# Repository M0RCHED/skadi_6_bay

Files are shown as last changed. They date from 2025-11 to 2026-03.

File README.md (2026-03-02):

# ⚡ Skadi 6-Bay Smart Charger — v1.0 

> Plateforme de gestion intelligente pour 6 packs Li-ion 2S (Excel 2EXL1505 / Skadi).
> Système open hardware permettant la charge et décharge automatique pour atteindre ~30% SoC (conformité IATA/UN 3480).

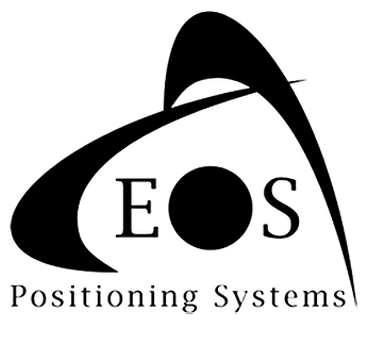
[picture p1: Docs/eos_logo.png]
EOS Logo


---

## 📋 Vue d'ensemble

Les transporteurs internationaux (UPS, FedEx, DHL, etc.) n'acceptent pas l'expédition de batteries Li-ion **> 30 % SoC** en raison des risques thermiques.

Le **Skadi 6-Bay Smart Charger** permet de **ramener automatiquement chaque batterie au seuil de ~30 % SoC**, qu'elle soit initialement trop basse (charge) ou trop haute (décharge via ELOAD externe).

### Fonctionnalités principales

- ✅ **6 baies indépendantes** avec contrôle charge/décharge par MOSFET
- ✅ **Supervision I²C** via multiplexeur TCA9548A + répéteurs TCA9803
- ✅ **Fuel gauge MAX17263** intégré dans chaque pack (SoC, température, tension)
- ✅ **Machine à états finie (FSM)** avec initialisation automatique ModelGauge m5 EZ
- ✅ **Télémétrie BLE** (HC-08) + UART + USB CDC
- ✅ **Affichage LED** par baie via driver PCA9634
- ✅ **Watchdog matériel** (WWDG) pour sécurité

---

## 🔧 Architecture matérielle

### Alimentation
- **Entrée**: 12V DC (fusible 12A rapide)
- **Buck 3.3V**: TPS562200 (12V → 3.3V, 2A)
- **Protection**: TVS, NTC, condensateurs bulk

### Microcontrôleur
- **MCU**: STM32F103C8Tx (ARM Cortex-M3, 48 pins)
- **Horloge**: 16 MHz (cristal externe HSE)
- **Watchdog**: WWDG (Window Watchdog) avec refresh toutes les 10ms
- **Interfaces**:
  - USB 2.0 Type-C (protection USBLC6-2SC6)
  - SWD (Tag-Connect TC2030-NL)
  - UART2 (115200 baud, BLE HC-08)
  - I²C1 (100 kHz)
  - ADC1 (mesure tension 12V)

### Gestion des baies (×6)

Chaque baie dispose de:
- **Commutation charge**: P-MOSFET AO4407A + driver N-MOSFET DMG2302U
- **Commutation décharge**: P-MOSFET AO4407A + driver N-MOSFET DMG2302U
- **Répéteur I²C**: TCA9803 (isolation 3.3V ↔ pack)
- **Protection**: Diodes 1N4148WT, résistances de limitation
- **Points de test**: CHG_GATE, DIS_GATE
- **Connecteur**: 2 broches pogo pins (BAT+/BAT-)

### Multiplexage I²C
- **Circuit**: TCA9548APWR (8 canaux, 6 utilisés)
- **Fonction**: Communication I²C individuelle avec chaque pack
- **Pull-ups**: 2.2kΩ sur bus principal, 10kΩ sur multiplexeur

### Pilotage des LEDs
- **Driver**: PCA9634PW (8 canaux PWM)
- **Résistances**: 680Ω par LED
- **Contrôle**: Via I²C depuis MCU

---

## 🧠 Architecture Firmware

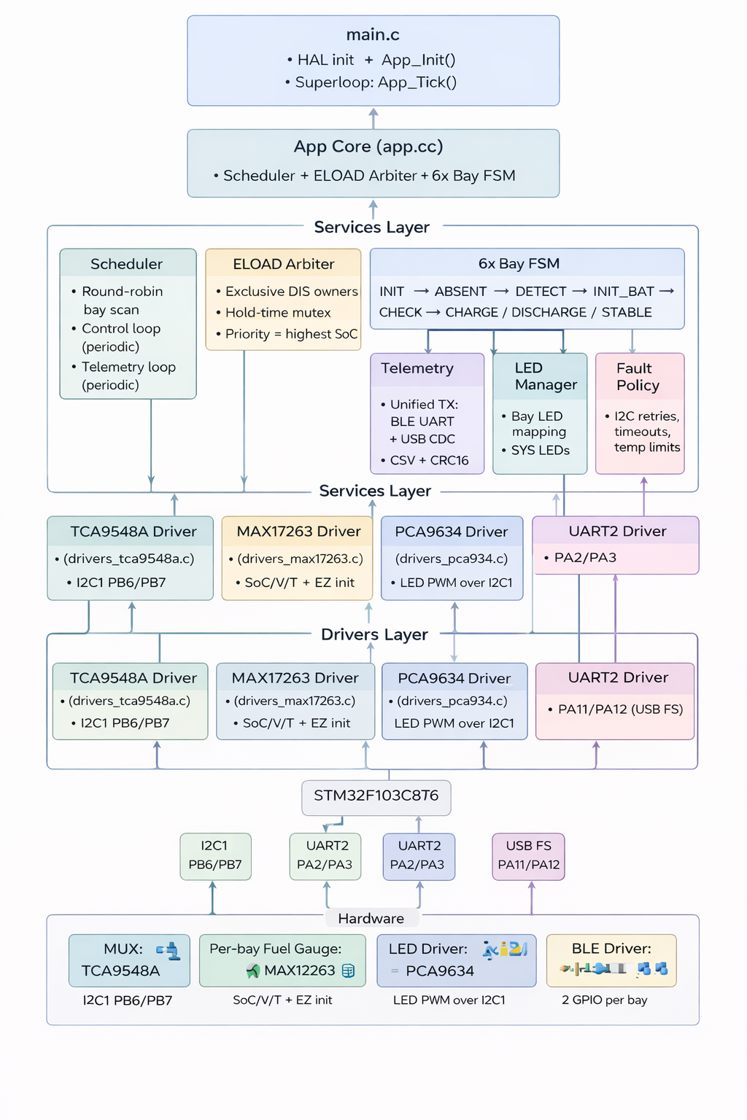
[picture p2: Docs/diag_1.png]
Diagramme d'architecture firmware


### Structure du code

```
firmware/
├── Core/
│   ├── Src/
│   │   ├── main.c              # Point d'entrée, init périphériques
│   │   ├── stm32f1xx_it.c      # Interruptions
│   │   └── system_stm32f1xx.c  # Config système
│   └── Inc/
├── App/
│   ├── app.c                   # Machine à états principale
│   ├── app_config.h            # Constantes (seuils, timeouts)
│   ├── board_io.c              # Abstraction GPIO/ADC
│   ├── drivers_tca9548a.c      # Driver MUX I²C
│   ├── drivers_max17263.c      # Driver fuel gauge
│   ├── drivers_pca9634.c       # Driver LEDs
│   ├── services_cmd.c          # Parser commandes BLE/UART
│   ├── services_led.c          # Logique LEDs
│   ├── services_telemetry.c    # Télémétrie UART/USB
│   └── services_identity.c     # UID unique STM32
└── USB_DEVICE/                 # Stack USB CDC
```

### Boucle principale (main.c)

```c
void main(void) {
  HAL_Init();
  SystemClock_Config();  // HSE 16MHz → PLL 48MHz
  
  // Init périphériques
  MX_GPIO_Init();
  MX_ADC1_Init();
  MX_I2C1_Init();        // 100kHz
  MX_USART2_UART_Init(); // 115200 baud
  MX_WWDG_Init();        // Watchdog
  MX_USB_DEVICE_Init();  // CDC
  
  App_Init(&g_app);
  HAL_UART_Receive_IT(&huart2, &ble_rx_byte, 1);
  
  while(1) {
    if ((HAL_GetTick() - t0) >= 10ms) {  // Tick 10ms
      t0 = HAL_GetTick();
      App_Tick(&g_app);                  // FSM principale
      HAL_WWDG_Refresh(&hwwdg);          // Feed watchdog
    }
  }
}
```

### Machine à états finie (FSM)

Le firmware implémente une FSM par baie avec **scan round-robin** (une baie à la fois, cycle de 5s/baie).

#### États de la FSM

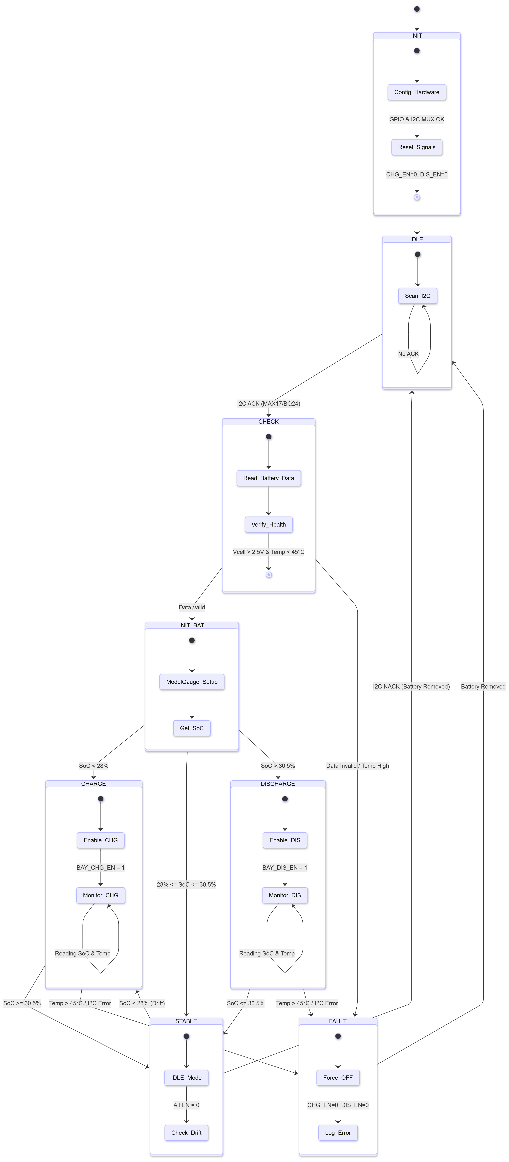
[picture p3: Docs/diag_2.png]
Diagramme FSM


#### Description des états

| État | Description | Transitions |
|---|---|---|
| **INIT** | Initialisation système, reset des GPIO | → ABSENT (pack absent)<br>→ CHECK (pack détecté) |
| **IDLE** | Pack non détecté (DET=0 ou I²C NACK) | → CHECK (insertion pack) |
| **CHECK** | Lecture I²C initiale, vérification température | → INIT_BAT (I²C OK)<br>→ FAULT (I²C fail > 3×) |
| **INIT_BAT** | **Initialisation ModelGauge m5 EZ**<br>• Appel `Gauge_EZ_Init()`<br>• Configuration fuel gauge | → CHARGE (SoC < 28%)<br>→ DISCHARGE (SoC > 30.5%)<br>→ STABLE (28% ≤ SoC ≤ 30.5%)<br>→ FAULT (erreur init) |
| **CHARGE** | 12V activé, charge CC/CV par BQ24610 | → STABLE (SoC ≥ 30.5%)<br>→ FAULT (timeout 25min, T>45°C) |
| **DISCHARGE** | ELOAD actif (une baie à la fois) | → STABLE (SoC ≤ 30.5%)<br>→ FAULT (timeout 20min, T>45°C) |
| **STABLE** | SoC autour de 30%, repos | → CHARGE (SoC < 28%)<br>→ DISCHARGE (SoC > 30.5%) |
| **FAULT** | Erreur (température, I²C, timeout) | → CHECK (récupération auto si T<40°C, I²C OK) |

### Paramètres d'exploitation (app_config.h)

```c
// Seuils SoC
#define SOC_LOW_START      28.0f    // Démarrer charge
#define SOC_STABLE_HIGH    30.5f    // Arrêter charge/décharge
#define SOC_DISCH_START    30.5f    // Démarrer décharge

// Seuils température
#define TEMP_MAX_C         45.0f    // Coupure sécurité
#define TEMP_RECOVER_C     40.0f    // Récupération auto

// Timeouts
#define CHG_TIMEOUT_MS     (25u * 60u * 1000u)  // 25 min
#define DIS_TIMEOUT_MS     (20u * 60u * 1000u)  // 20 min

// Périodes
#define SCAN_PERIOD_MS_PER_BAY  5000u   // 5s/baie
#define CTRL_PERIOD_MS          100u    // 100ms (FSM)
#define TELEMETRY_PERIOD_MS     5000u   // 5s

// I²C
#define I2C_RETRY_MAX          3u
#define I2C_RETRY_DELAY_MS     50u
```

### Arbitrage ELOAD

**Règle**: Une seule baie à la fois peut être connectée à l'ELOAD.

```c
void eload_select_set(app_t *a, uint8_t allow_dis[BAY_COUNT])
{
  // Sélectionner jusqu'à eload_slots baies (1 par défaut)
  // Prioriser la baie avec le SoC le plus élevé
  
  for (uint8_t slot = 0; slot < a->eload_slots; slot++) {
    float best_soc = SOC_DISCH_START;
    int best_bay = -1;
    
    for (uint8_t i = 0; i < BAY_COUNT; i++) {
      if (allow_dis[i]) continue;           // Déjà sélectionnée
      if (!bay[i].present || !bay[i].i2c_ok) continue;
      if (bay[i].state == BAY_S_FAULT) continue;
      if (bay[i].temp_c >= TEMP_MAX_C) continue;
      if (bay[i].soc <= SOC_DISCH_START) continue;
      
      if (bay[i].soc > best_soc) {
        best_soc = bay[i].soc;
        best_bay = i;
      }
    }
    
    if (best_bay >= 0) allow_dis[best_bay] = 1;
  }
}
```

### Initialisation ModelGauge m5 EZ

**État INIT_BAT**: Après détection du pack et lecture I²C réussie, le firmware initialise le fuel gauge:

```c
// drivers_max17263.c
HAL_StatusTypeDef Gauge_EZ_Init(void)
{
  // 1. Soft reset (optionnel)
  // i2c_w16(0x60, 0x000F);  // Command = 0x000F
  // HAL_Delay(200);
  
  // 2. Configuration ModelGauge m5 EZ
  // i2c_w16(0xDB, 0x8000);  // ModelCfg = 0x8000 (EZ mode)
  // HAL_Delay(2000);        // Attendre convergence modèle
  
  // 3. Paramètres pack (exemples)
  // i2c_w16(0x18, 3300);    // DesignCap = 3300 mAh
  // i2c_w16(0x23, 8400);    // VEmpty = 5.0V (2×2.5V)
  
  // Pour l'instant, retour OK (à compléter selon datasheet)
  return HAL_OK;
}
```

**Note**: L'implémentation complète sera finalisée avec les paramètres exacts du pack Excel 2EXL1505.

### Télémétrie

Format CSV avec CRC16-CCITT envoyé toutes les 5s par baie:

```
UID,<24_hex_chars>,TS,<ms>,BAY,<1-6>,ST,<état>,SOC_D10,<0.1%>,VCELL_MV,<mV>,TEMP_D10,<0.1°C>,PRES,<0|1>,I2C,<0|1>,ERR,<code>,ELOADS,<slots>,VIN_CV,<cV>,CRC,<hex>
```

**Exemple**:
```
UID,2A01C3F08B1D77AA0019FF10,TS,123456,BAY,3,ST,DIS,SOC_D10,472,VCELL_MV,7730,TEMP_D10,314,PRES,1,I2C,1,ERR,0,ELOADS,1,VIN_CV,1215,CRC,A3F2
```

### Commandes BLE/UART

Format texte simple:

```
ELOADS=<1-6>   # Nombre de baies ELOAD simultanées
MODE=30        # Mode ~30% SoC (défaut)
MODE=100       # Mode charge 100%
```

---

## 📊 Schémas du PCB

Le projet contient 7 pages de schémas KiCad:

1. **Page 1**: Vue d'ensemble (hiérarchie des feuilles)
2. **Page 2**: Alimentation 12V → Buck 3.3V
3. **Page 3**: MCU STM32F103C8T + USB + SWD + BLE
4. **Page 4**: Multiplexeur I²C TCA9548A
5. **Page 5**: Buck converter 3.3V (TPS562200)
6. **Page 6**: Baie #1 (répété ×6)
7. **Page 7**: Driver LEDs PCA9634

---

## 🛠️ Composants principaux

| Référence | Composant | Quantité | Description |
|---|---|---|---|
| U1 | TPS562200 | 1 | Buck 12V→3.3V (2A) |
| U2 | TCA9803 | 6 | Répéteur I²C par baie |
| U3 | USBLC6-2SC6 | 1 | Protection USB |
| U4 | STM32F103C8Tx | 1 | MCU principal (48MHz) |
| U6 | TCA9548APWR | 1 | MUX I²C 8 canaux |
| IC1 | PCA9634PW | 1 | Driver LED 8 canaux |
| Q_CHG1/2 | AO4407A | 12 | P-MOSFET charge (×2/baie) |
| Q_DIS2 | AO4407A | 6 | P-MOSFET décharge |
| Q_CHG/DIS_DRV | DMG2302U | 12 | N-MOSFET driver |
| F1 | Fusible 12A | 1 | Protection entrée |
| D1 | TVS | 1 | Protection surtension |
| Y1 | Cristal 16MHz | 1 | Horloge externe HSE |
| L1 | Inductance 3.3µH | 1 | Buck converter |

---

## 🔌 Pinout MCU (STM32F103C8T)

### Contrôle baies
| Pin | Signal | Fonction |
|-----|---|---|
| PA0 | BAY1_CHG_EN | Enable charge baie 1 |
| PA1 | BAY2_CHG_EN | Enable charge baie 2 |
| PA2 | BAY3_CHG_EN | Enable charge baie 3 |
| PA3 | BAY4_CHG_EN | Enable charge baie 4 |
| PA4 | BAY1_DIS_EN | Enable décharge baie 1 |
| PA5 | BAY2_DIS_EN | Enable décharge baie 2 |
| PB0 | BAY5_CHG_EN | Enable charge baie 5 |
| PB1 | BAY6_CHG_EN | Enable charge baie 6 |
| PB10 | BAY6_DIS_EN | Enable décharge baie 6 |
| PB11 | BAY5_DIS_EN | Enable décharge baie 5 |
| PB12 | BAY4_DIS_EN | Enable décharge baie 4 |
| PB13 | BAY3_DIS_EN | Enable décharge baie 3 |

### Communication
| Pin | Signal | Fonction |
|-----|---|---|
| PB6 | I2C1_SCL | Horloge I²C (100kHz) |
| PB7 | I2C1_SDA | Données I²C |
| PA9 | UART_TX | TX vers BLE HC-08 |
| PA10 | UART_RX | RX depuis BLE HC-08 |
| PA11 | USB_D- | USB 2.0 D- |
| PA12 | USB_D+ | USB 2.0 D+ |

### Programmation/Debug
| Pin | Signal | Fonction |
|-----|---|---|
| PA13 | SWDIO | Serial Wire Debug I/O |
| PA14 | SWCLK | Serial Wire Clock |
| PB3 | SWO | Serial Wire Output |
| NRST | NRST | Reset (connecté à superviseur) |

### ADC
| Pin | Signal | Fonction |
|-----|---|---|
| PA0 | ADC_CH0 | Mesure tension 12V (diviseur 133k/33k) |

---

## 📐 Diagramme d'architecture

```
       12V DC Input (12A fusible)
              │
      ┌───────┴───────────┐
      │   Protection      │
      │ • TVS SMBJ15A     │
      │ • Bulk caps       │
      │                   │
      └───────┬───────────┘
              │
      ┌───────┴───────────────────────────────────┐
      │                                           │
      ▼                                           ▼
┌─────────────┐                         ┌──────────────────┐
│ Buck 3.3V   │                         │  6× Bay Switches │
│ TPS562200   │           ┌────────────►│      AO4407A     │
│ (2A)        │     ┌─────┴─────┐       │  (12V high-side) │
└──────┬──────┘     │ DMG2302U  │       └────────┬─────────┘
       │            └─────┬─────┘                │
       ▼                  │                      ▼
┌──────────────────┐      │GPIO x6        ┌──────────────┐
│  STM32F103C8T    │      │               │ Pogo Pins ×6 │
│  • 48MHz         ├──────┤               │ (Batt packs) │
│  • WWDG          │      │               └──────────────┘
│  • 10ms tick     │      │                       │
└────┬─────────────┘      │                       │
     │                    │                       │
	 │                    │                       │
	 │              ┌─────┴─────┐                 │
	 │              │ DMG2302U  ├───────┐         │
	 │              └───────────┘       │         │
	 │                                  ▼         │
	 │                            ┌───────────┐   │ 
	 │                            │ 6 Switches│   │	 
	 │                            │ to ELOAD  │   │
     │                            └───────────┘   │
     │                                            │
     │                                            │
     ├──► TCA9548A (I²C MUX)                      │
	 │         │                                  │	 
	 │         │                                  │
     │         ├──► TCA9803 ×6 ───────────────────┘
     │         │     (Buffers)
     │         │
     │         └──► PCA9634 (LED driver)
     │
	 ├──► ADC
	 │
     ├──► USB Type-C
     │
     └──► UART2 → HC-08 (BLE)
```

---

## 🚀 Utilisation

### Programmation (SWD)

1. Connecter programmeur ST-Link au header Tag-Connect (J2)
2. Pins: VCC, GND, SWDIO, SWCLK, NRST, SWO
3. Flasher avec STM32CubeIDE ou OpenOCD

```bash
# Exemple OpenOCD
openocd -f interface/stlink.cfg -f target/stm32f1x.cfg \
  -c "program firmware.elf verify reset exit"
```

### Configuration I²C

- **TCA9548A** (MUX): Adresse 0x70 (A2=A1=A0=0)
- **MAX17263** (Gauge): Adresse 0x6C (sur chaque canal MUX)
- **PCA9634** (LEDs): Adresse 0x15 (A6-A0 configurables)

### Contrôle via BLE/UART

Connecter terminal série (115200 baud, 8N1):

```
ELOADS=2       # Autoriser 2 baies ELOAD simultanées
MODE=30        # Mode ~30% SoC (défaut)
MODE=100       # Mode charge 100%
```

### Télémétrie

Recevoir les trames CSV toutes les 5s:

```python
import serial

ser = serial.Serial('/dev/ttyUSB0', 115200)
while True:
    line = ser.readline().decode('utf-8').strip()
    print(line)
    # Parser: UID,xxx,TS,yyy,BAY,z,...
```

---

## ⚡ Spécifications électriques

| Paramètre | Valeur | Notes |
|---|---|---|
| Tension d'entrée | 12V DC ±10% | 10.8V min, 13.2V max |
| Courant max | 12A | Fusible rapide |
| Tension logique | 3.3V ±5% | Buck TPS562200 |
| Courant par baie (charge) | ~1.1A @ 12V | Via BQ24610 interne pack |
| Fréquence I²C | 100 kHz | Standard mode |
| Fréquence UART | 115200 baud | 8N1, BLE HC-08 |
| Watchdog timeout | ~50ms | WWDG, refresh 10ms |
| Horloge système | 48 MHz | HSE 16MHz + PLL×6 |

---

## 🔒 Protections & Sécurité

| Protection | Implémentation | Réaction |
|---|---|---|
| **Surtension 12V** | TVS SMBJ15A | Écrêtage transitoires |
| **Surcourant** | Fusible 12A rapide | Coupure permanente |
| **Température pack** | MAX17263 + NTC | OFF charge/décharge si >45°C |
| **Watchdog** | WWDG matériel | Reset MCU si crash firmware |
| **Timeout charge** | Software, 25 min | → FAULT |
| **Timeout décharge** | Software, 20 min | → FAULT |
| **Erreur I²C** | 3 retry + isolation baie | → FAULT si persiste |
| **USB** | USBLC6-2SC6 | ESD protection |

---

## 🧪 Tests & Validation

### Checklist matérielle

- [ ] Continuité pistes 12V / GND
- [ ] Court-circuits (test DRC KiCad)
- [ ] Polarité condensateurs électrolytiques
- [ ] Orientation MOSFETs, diodes, ICs
- [ ] Soudure pogo pins

### Checklist firmware

- [ ] Communication I²C avec TCA9548A
- [ ] Sélection canaux MUX (0-5)
- [ ] Lecture MAX17263 (SoC, V, T)
- [ ] Initialisation ModelGauge m5 EZ
- [ ] Commutation MOSFETs charge/décharge
- [ ] Télémétrie UART/USB
- [ ] Watchdog (test crash volontaire)
- [ ] LEDs (états FSM)
- [ ] Commandes BLE

### Procédure de test

1. **Test bench**:
   - Alim 12V/12A
   - 6× packs Skadi (SoC variés: 20%, 35%, 50%, etc.)
   - ELOAD programmable (mode CC, 0.5-1A)
   - Multimètre, oscilloscope
   - Terminal série (UART/BLE)

2. **Scénarios**:
   - Pack vide (10%) → CHARGE → STABLE (30%)
   - Pack plein (80%) → DISCHARGE → STABLE (30%)
   - Insertion/retrait pack → transitions ABSENT/CHECK
   - Surchauffe simulée (chauffer NTC) → FAULT
   - Déconnexion I²C → FAULT après 3 retry

---

## 📂 Structure du dépôt

```
Skadi-6Bay-Charger/
├── hardware/
│   ├── 6_bay_charg.kicad_pcb       # Layout PCB
│   ├── 6_bay_charg.kicad_sch       # Schéma racine
│   ├── Power.kicad_sch             # Alim 12V/3.3V
│   ├── MCU.kicad_sch               # MCU + USB + SWD
│   ├── MUX.kicad_sch               # TCA9548A
│   ├── Buck_3.3V.kicad_sch         # TPS562200
│   ├── bay1.kicad_sch              # Baie type
│   ├── LEDs_driver.kicad_sch       # PCA9634
│   └── bom/                        # Bill of Materials
├── firmware/
│   ├── Core/
│   │   ├── Src/main.c
│   │   └── Inc/main.h
│   ├── App/
│   │   ├── app.c                   # FSM principale
│   │   ├── app_config.h            # Constantes
│   │   ├── board_io.c              # GPIO/ADC
│   │   ├── drivers_tca9548a.c
│   │   ├── drivers_max17263.c
│   │   ├── drivers_pca9634.c
│   │   ├── services_cmd.c
│   │   ├── services_led.c
│   │   ├── services_telemetry.c
│   │   └── services_identity.c
│   └── USB_DEVICE/
├── docs/
│   ├── eos_logo.png
│   ├── datasheets/
│   └── images/
├── README.md
└── LICENSE
```

---

## 🔧 Développement

### Prérequis

- **Hardware**: ST-Link V2/V3, alimentation 12V/12A
- **Software**:
  - STM32CubeIDE (ou Keil, IAR)
  - KiCad 7.0+
  - Terminal série (PuTTY, minicom)

### Build firmware

```bash
cd firmware
# Importer projet dans STM32CubeIDE
# Build → Release
# Flash via ST-Link
```

### Modification schémas

```bash
cd hardware
kicad 6_bay_charg.kicad_pro
# Modifier schémas
# Générer netlist
# Update PCB
```

---

## 🐛 Dépannage

| Problème | Cause probable | Solution |
|---|---|---|
| Pas de détection pack | Pogo pins mal alignés | Vérifier mécanique, continuité |
| I²C timeout | Pull-ups manquants/trop faibles | Ajouter 2.2kΩ, vérifier soudures TCA9803 |
| SoC erroné | MAX17263 non initialisé | Vérifier `Gauge_EZ_Init()`, lire ModelCfg |
| Reset MCU fréquent | Watchdog non rafraîchi | Vérifier tick 10ms
...

## 📌 Limitations connues & évolutions prévues

### Limitations actuelles (v1.0)

- 🔸 **Une seule ELOAD active à la fois**  
  Par défaut, une seule baie peut être connectée à la charge électronique externe pour la décharge.  
  👉 Ce comportement est **logiciel** et **configurable**.

- 🔸 **Pas de stockage persistant des statistiques**  
  Les cycles charge/décharge, fautes et durées ne sont pas encore sauvegardés en Flash interne.

- 🔸 **Interface utilisateur minimale**  
  Le système est volontairement headless (BLE / UART / USB CDC uniquement).

---

### Évolutions prévues (roadmap)

- 🔧 **Décharge multi-baies configurable**  
  Possibilité d’autoriser **N baies simultanées en décharge** (`ELOADS=<1..6>`), avec :
  - arbitrage dynamique,
  - respect du budget PSU,
  - priorisation par SoC.

- 💾 **Journalisation Flash (event log)**  
  Stockage persistant :
  - erreurs par baie,
  - durées de charge/décharge,
  - nombre de cycles.

- 📊 **Interface PC / Web**  
  - Outil desktop (USB CDC) ou web (BLE) pour :
    - monitoring temps réel,
    - export CSV,
    - mise à jour firmware.

- 🌡️ **Gestion thermique avancée**
  - Ventilateur PWM proportionnel,
  - réduction automatique du nombre de baies actives en cas de montée thermique.

- 🔐 **Sécurité & production**
  - CRC firmware,
  - versioning hardware/firmware,
  - numéro de série exposé via BLE/USB.

---

## 🧾 Conformité & usage prévu

- ✔️ **Conformité IATA / UN 3480**  
  Le mode **~30 % SoC** est spécifiquement conçu pour le transport aérien sécurisé.

- ⚠️ **Usage interne / professionnel**  
  Ce projet est destiné à un **environnement contrôlé** ( production, maintenance).  

---

## 📄 Licence

Ce projet est publié sous licence **MIT** :

- Utilisation libre (personnelle / commerciale)

Voir le fichier `LICENSE` pour le texte complet.

---

## 🤝 Contributions

Les contributions sont bienvenues :

- amélioration firmware (FSM, drivers),
- validation thermique,
- optimisation hardware,
- outils de monitoring.

Merci d’ouvrir une **issue** ou une **pull request** avec une description claire.

---

## ✍️ Auteur

**Takiyeddin Gherras**  

© 2026 EOS Positioning Systems

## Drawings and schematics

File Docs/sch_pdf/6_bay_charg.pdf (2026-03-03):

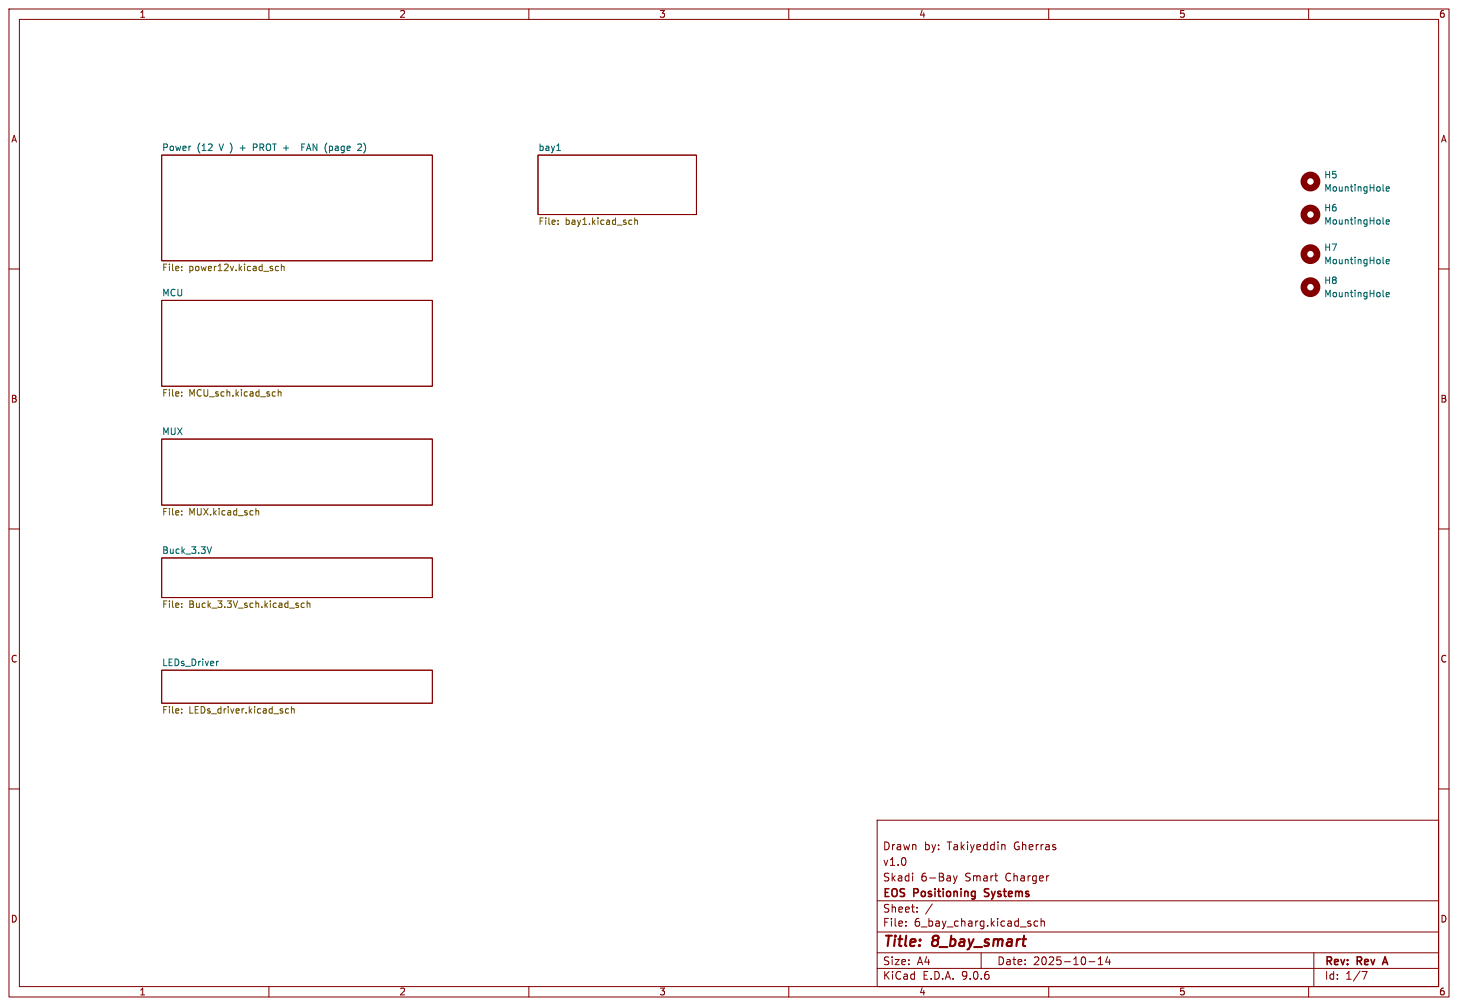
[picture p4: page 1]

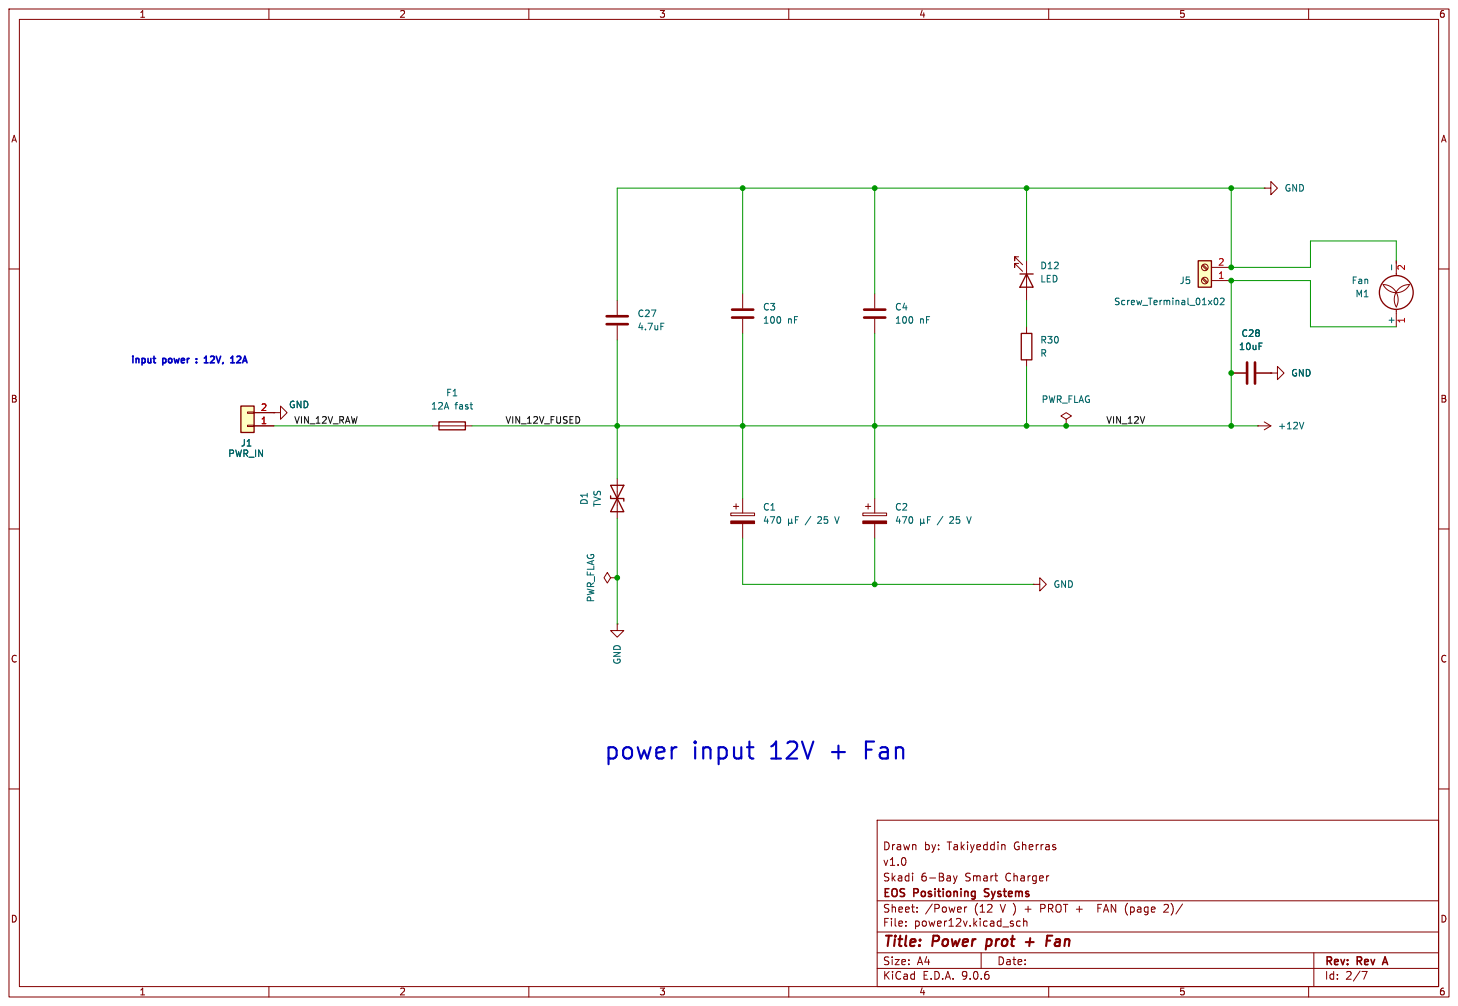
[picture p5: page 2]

Id: 2/7 Title: Power prot + Fan

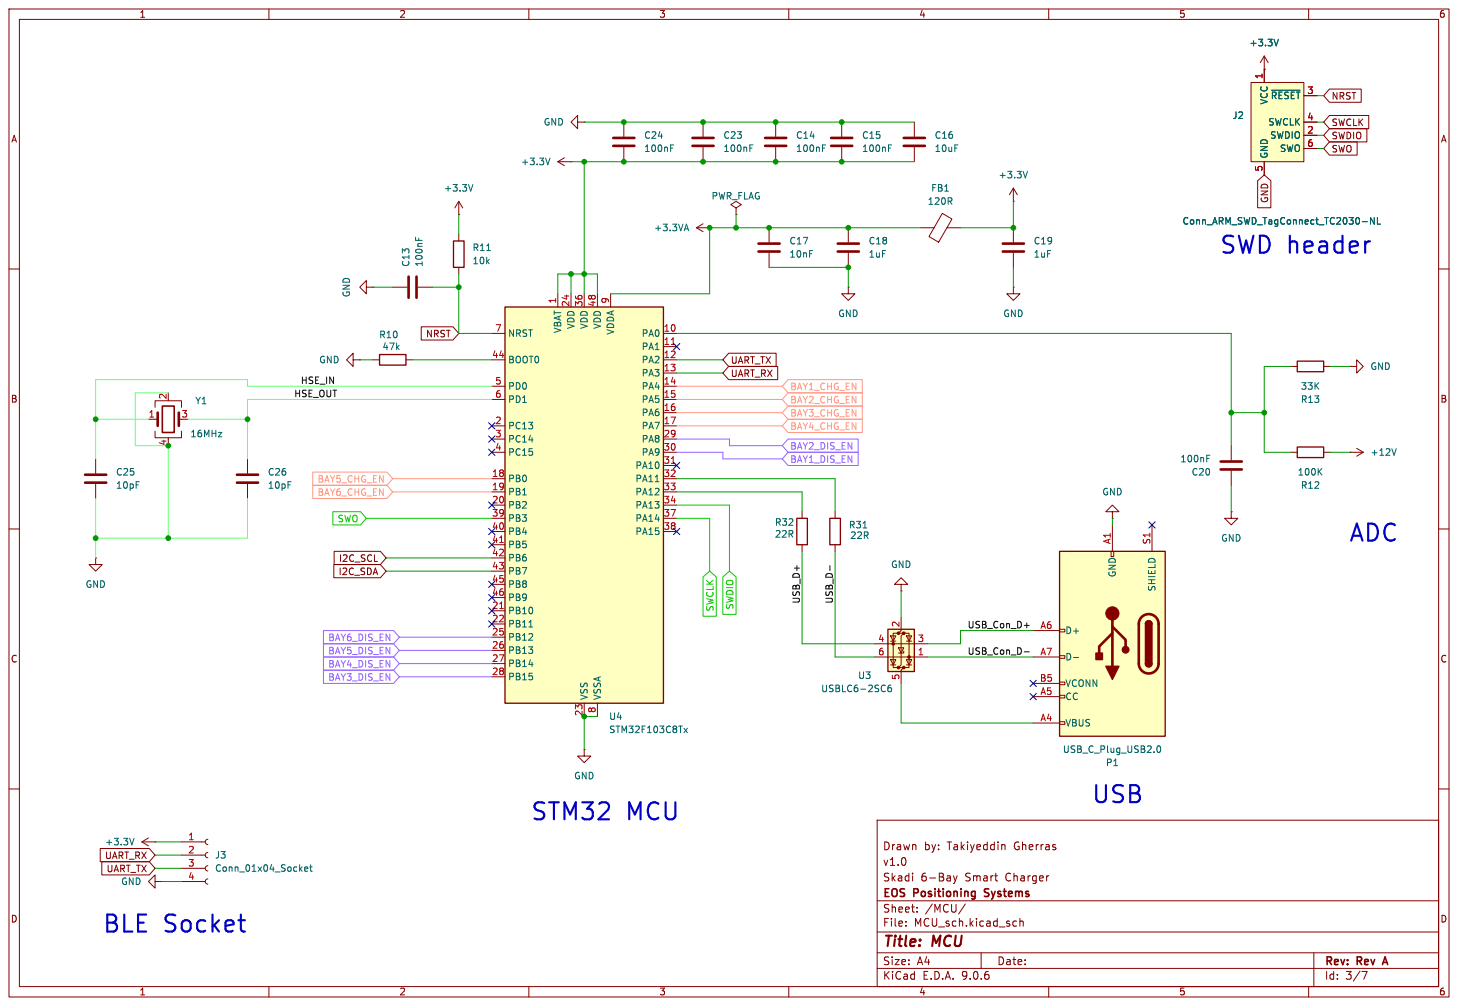
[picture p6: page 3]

5 ~{RESET}3 SWCLK 4 SWDIO 2 SWO 6 +3.3V

5 ~{RESET}3 SWCLK 4 SWDIO 2 SWO 6

1 VDD 24 VDD 36 VSS 23 VDD 48 VSSA

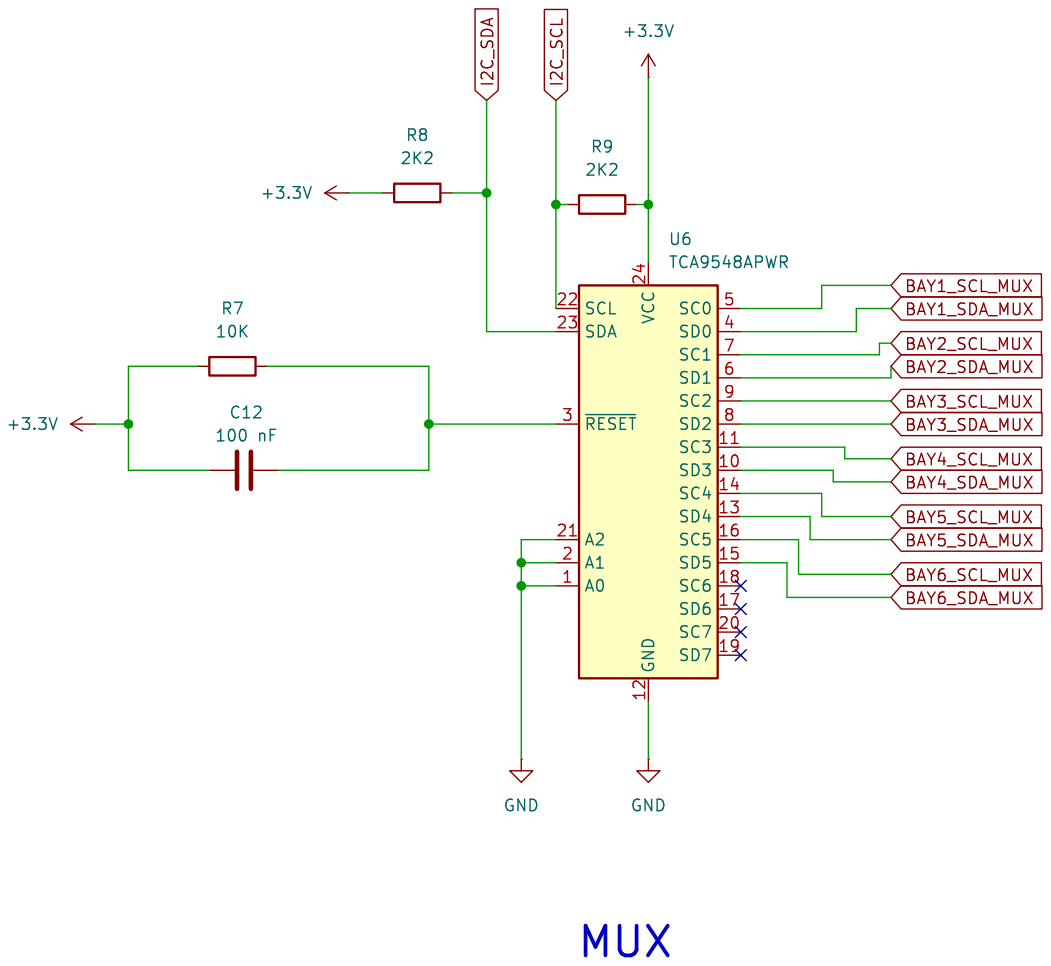
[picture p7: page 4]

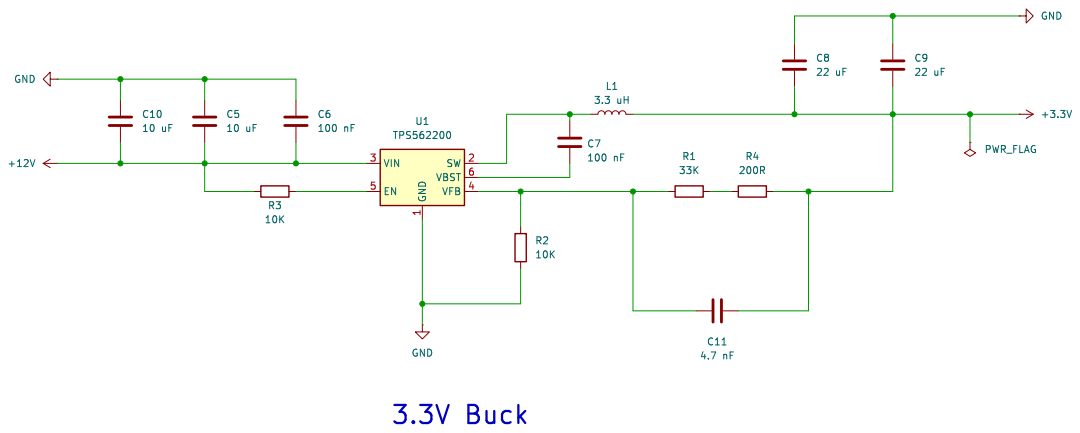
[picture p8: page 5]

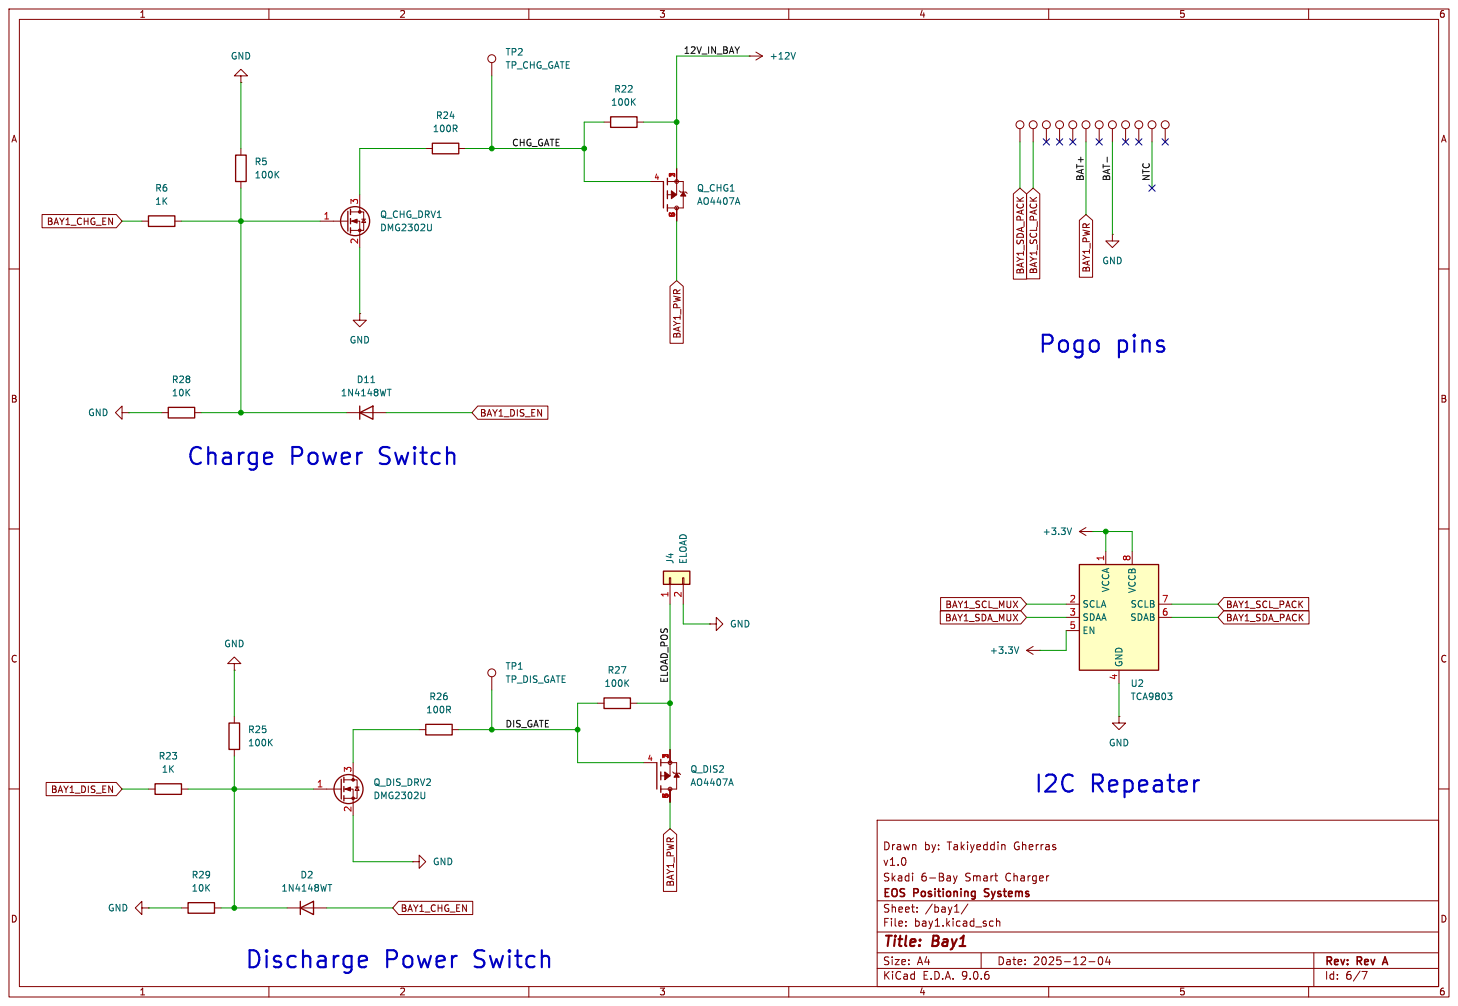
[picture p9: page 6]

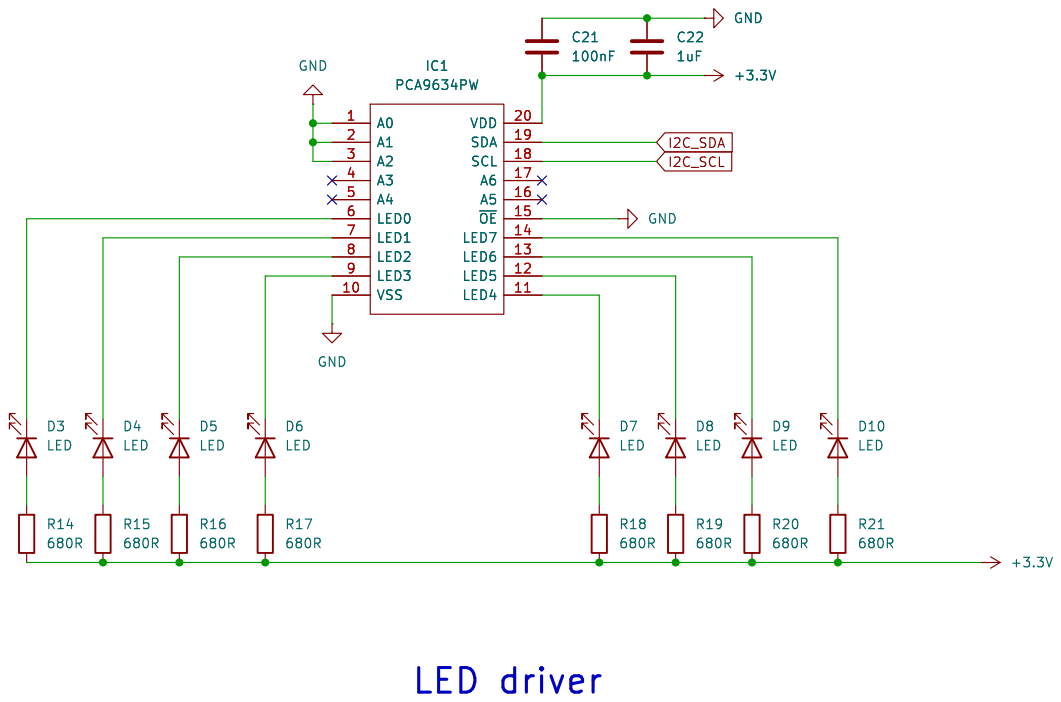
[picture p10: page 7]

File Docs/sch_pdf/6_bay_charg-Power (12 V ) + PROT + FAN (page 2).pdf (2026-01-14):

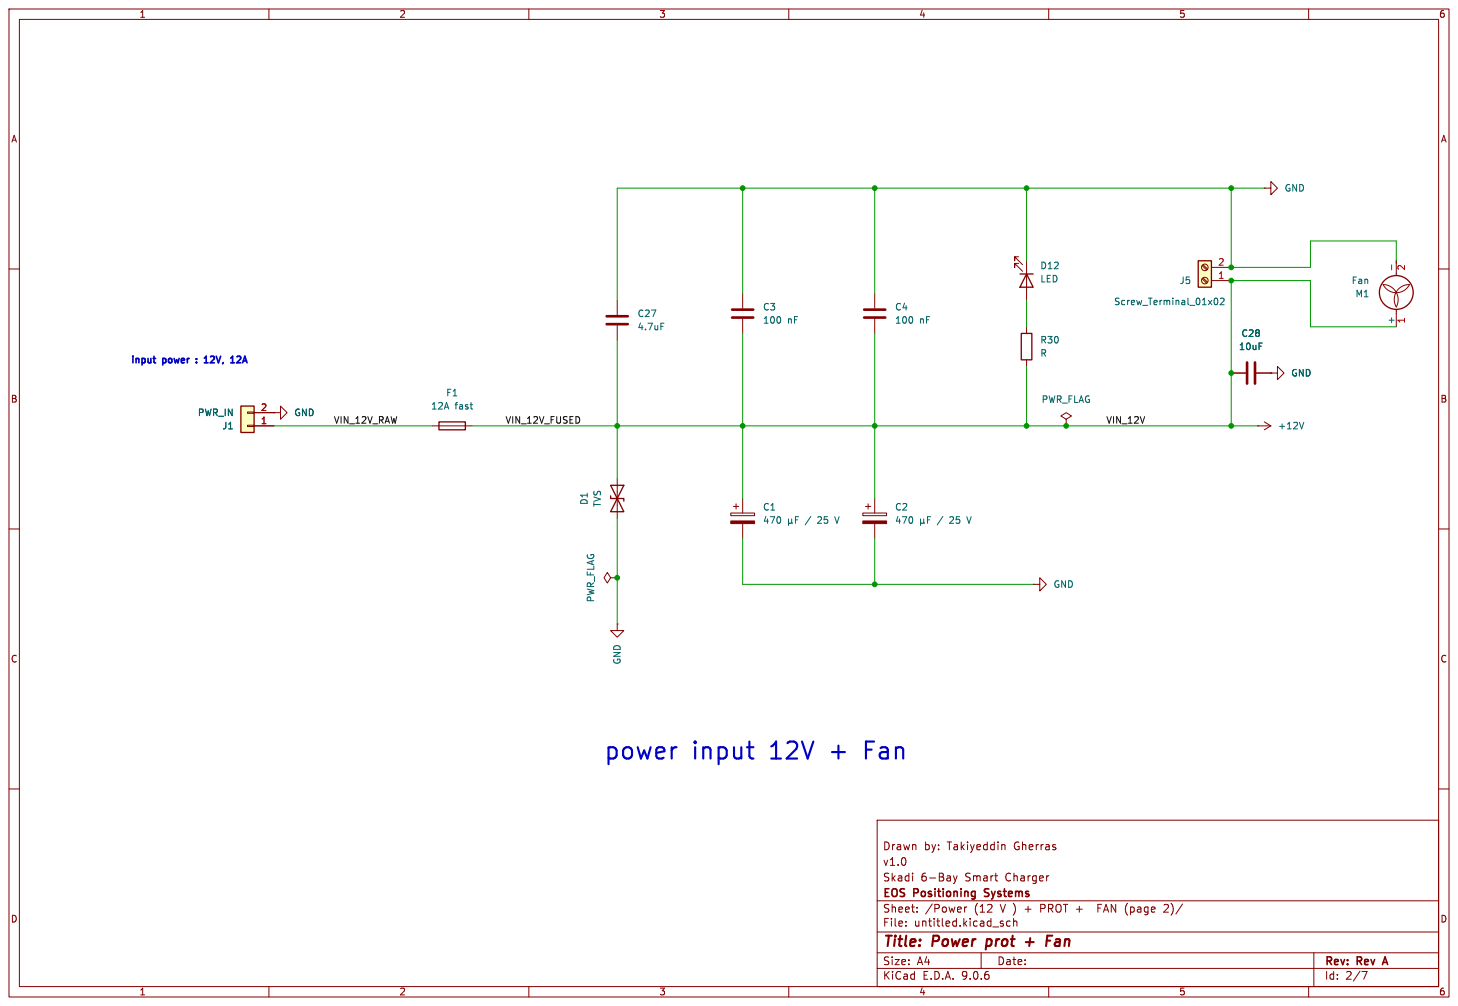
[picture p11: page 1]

Id: 2/7 Title: Power prot + Fan


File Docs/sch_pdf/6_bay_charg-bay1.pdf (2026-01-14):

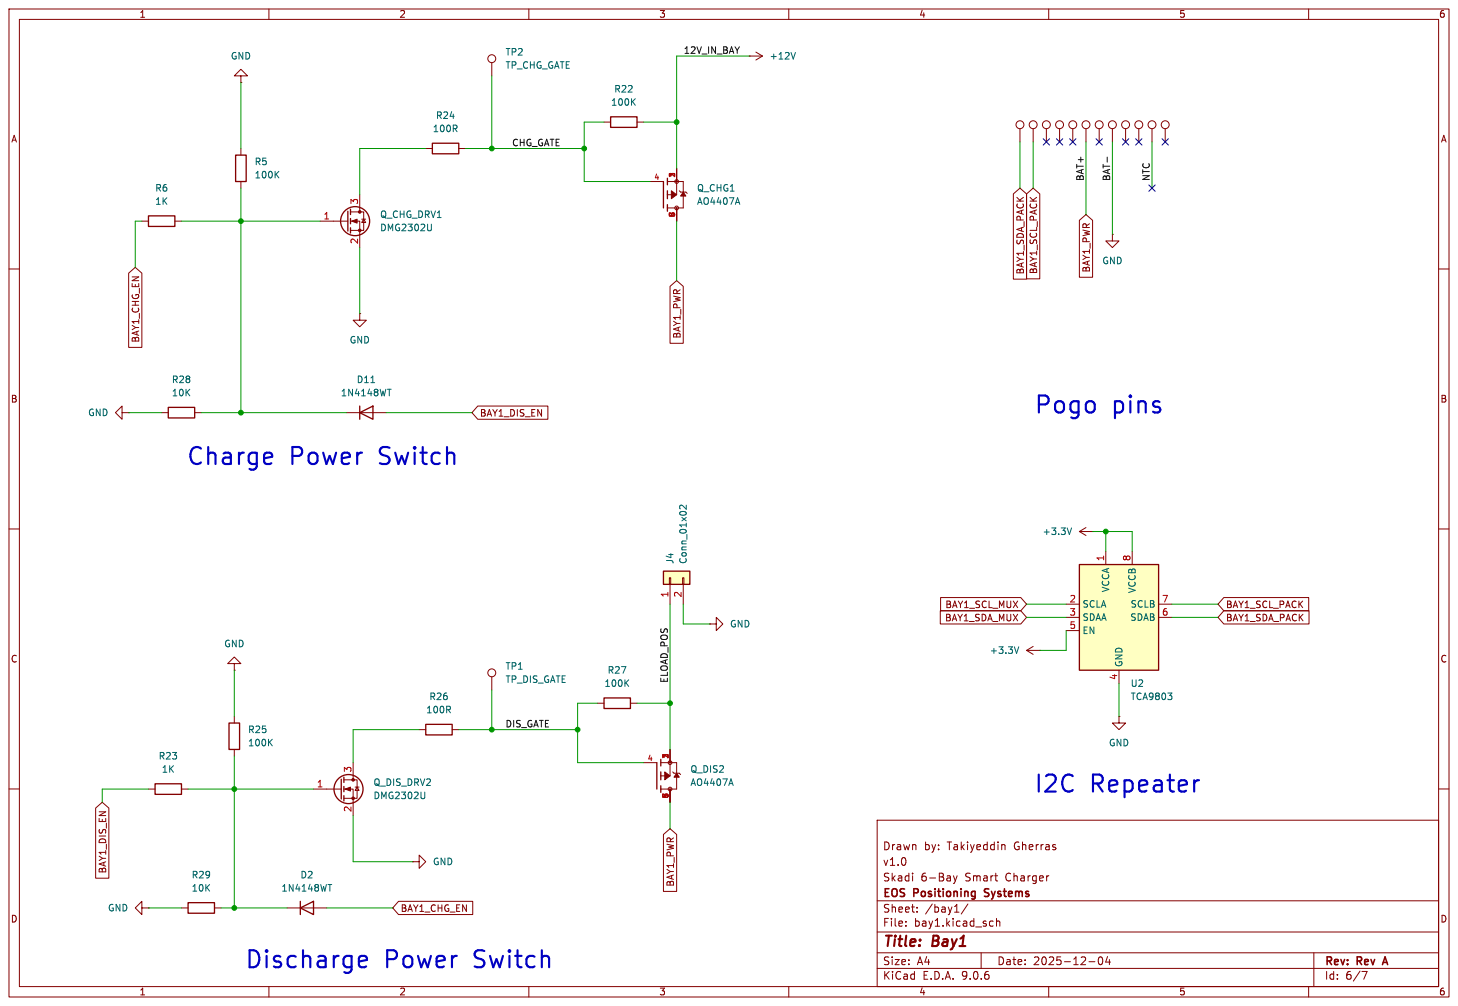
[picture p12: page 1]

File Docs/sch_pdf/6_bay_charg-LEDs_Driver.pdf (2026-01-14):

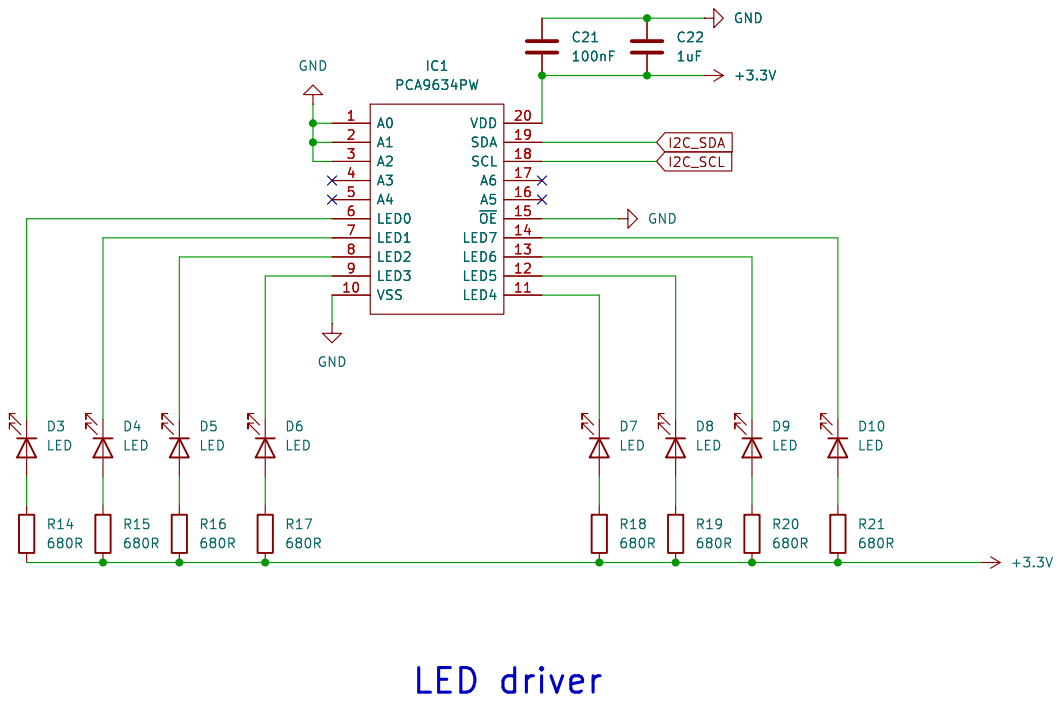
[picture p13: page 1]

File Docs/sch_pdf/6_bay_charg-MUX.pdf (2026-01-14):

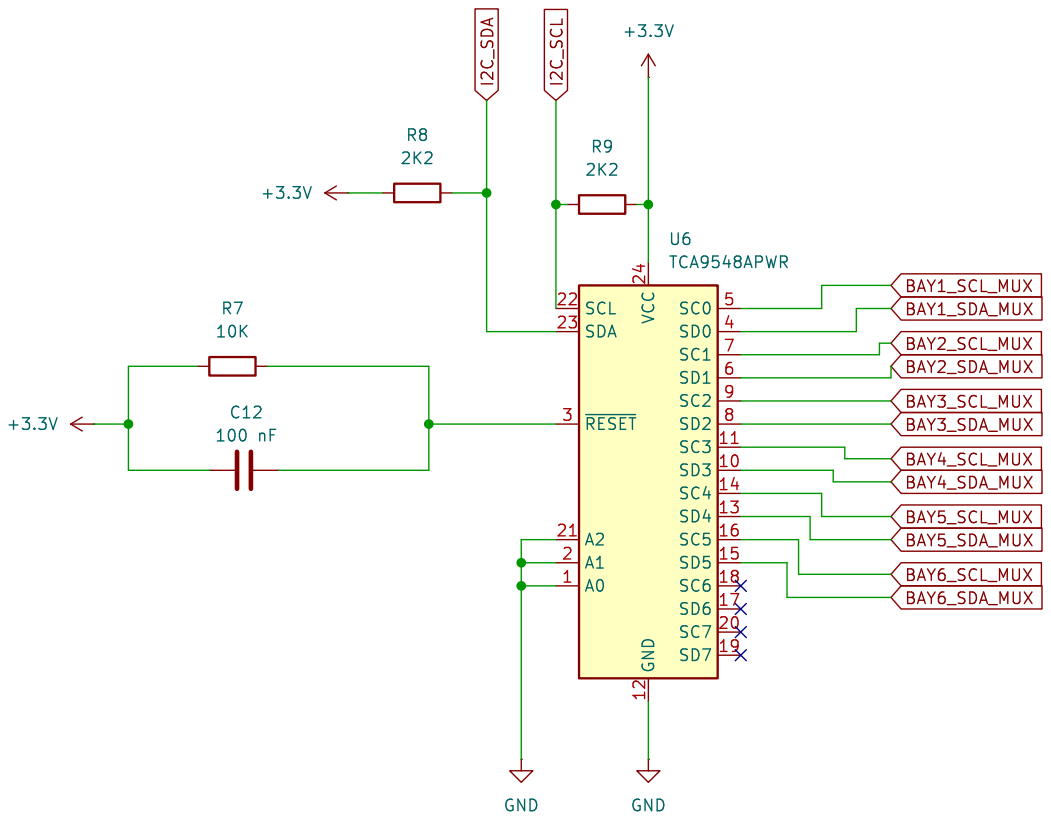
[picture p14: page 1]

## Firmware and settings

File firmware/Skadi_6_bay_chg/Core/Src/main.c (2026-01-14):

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
/* Includes ------------------------------------------------------------------*/
#include "main.h"
#include "usb_device.h"

/* USER CODE BEGIN Includes */
#include "app.h"
#include "services_cmd.h"
/* USER CODE END Includes */

ADC_HandleTypeDef hadc1;

I2C_HandleTypeDef hi2c1;

UART_HandleTypeDef huart2;

WWDG_HandleTypeDef hwwdg;

/* USER CODE BEGIN PV */
app_t g_app;
static uint8_t ble_rx_byte;
/* USER CODE END PV */

void SystemClock_Config(void);
static void MX_GPIO_Init(void);
static void MX_ADC1_Init(void);
static void MX_I2C1_Init(void);
static void MX_USART2_UART_Init(void);
static void MX_WWDG_Init(void);
/* USER CODE BEGIN 0 */

void HAL_UART_RxCpltCallback(UART_HandleTypeDef *huart)
{
  if (huart->Instance == USART2) {
    Cmd_Ingest(&g_app, &ble_rx_byte, 1);
    (void)HAL_UART_Receive_IT(&huart2, &ble_rx_byte, 1);
  }
}

/* USER CODE END 0 */

/**
  * @brief  The application entry point.
  * @retval int
  */
int main(void)
{

  /* MCU Configuration--------------------------------------------------------*/

  /* Reset of all peripherals, Initializes the Flash interface and the Systick. */
  HAL_Init();

  /* Configure the system clock */
  SystemClock_Config();

  /* Initialize all configured peripherals */
  MX_GPIO_Init();
  MX_ADC1_Init();
  MX_I2C1_Init();
  MX_USART2_UART_Init();
  MX_WWDG_Init();
  MX_USB_DEVICE_Init();
  /* USER CODE BEGIN 2 */
  App_Init(&g_app);
  (void)HAL_UART_Receive_IT(&huart2, &ble_rx_byte, 1);
  /* USER CODE END 2 */

  /* Infinite loop */
  /* USER CODE BEGIN WHILE */
  while (1)
  {
    /* USER CODE END WHILE */

    /* 10ms scheduler tick */
    static uint32_t t0 = 0;
    uint32_t now = HAL_GetTick();

    if ((uint32_t)(now - t0) >= 10u) {
      t0 = now;

      /* Main application state machine */
      App_Tick(&g_app);

      /* Feed watchdog (WWDG) */
      (void)HAL_WWDG_Refresh(&hwwdg);
    }


    /* USER CODE BEGIN 3 */
  }
  /* USER CODE END 3 */
}

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


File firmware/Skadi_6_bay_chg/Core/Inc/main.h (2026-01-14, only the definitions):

#define BAY1_CHG_EN_Pin GPIO_PIN_4
#define BAY1_CHG_EN_GPIO_Port GPIOA
#define BAY2_CHG_EN_Pin GPIO_PIN_5
#define BAY2_CHG_EN_GPIO_Port GPIOA
#define BAY3_CHG_EN_Pin GPIO_PIN_6
#define BAY3_CHG_EN_GPIO_Port GPIOA
#define BAY4_CHG_EN_Pin GPIO_PIN_7
#define BAY4_CHG_EN_GPIO_Port GPIOA
#define BAY5_CHG_EN_Pin GPIO_PIN_0
#define BAY5_CHG_EN_GPIO_Port GPIOB
#define BAY6_CHG_EN_Pin GPIO_PIN_1
#define BAY6_CHG_EN_GPIO_Port GPIOB
#define BAY6_DIS_EN_Pin GPIO_PIN_12
#define BAY6_DIS_EN_GPIO_Port GPIOB
#define BAY5_DIS_EN_Pin GPIO_PIN_13
#define BAY5_DIS_EN_GPIO_Port GPIOB
#define BAY4_DIS_EN_Pin GPIO_PIN_14
#define BAY4_DIS_EN_GPIO_Port GPIOB
#define BAY3_DIS_EN_Pin GPIO_PIN_15
#define BAY3_DIS_EN_GPIO_Port GPIOB
#define BAY2_DIS_EN_Pin GPIO_PIN_8
#define BAY2_DIS_EN_GPIO_Port GPIOA
#define BAY1_DIS_EN_Pin GPIO_PIN_9
#define BAY1_DIS_EN_GPIO_Port GPIOA

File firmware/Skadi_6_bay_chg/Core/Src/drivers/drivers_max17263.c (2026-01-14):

#include "drivers_max17263.h"
#include "board_io.h"

static HAL_StatusTypeDef i2c_r16(uint8_t reg, uint16_t *out)
{
  uint8_t b[2];
  if (HAL_I2C_Master_Transmit(&hi2c1, MAX17263_ADDR, &reg, 1, 80) != HAL_OK) return HAL_ERROR;
  if (HAL_I2C_Master_Receive(&hi2c1, MAX17263_ADDR, b, 2, 80) != HAL_OK) return HAL_ERROR;
  *out = (uint16_t)(b[0] | (b[1] << 8));
  return HAL_OK;
}
static HAL_StatusTypeDef i2c_w16(uint8_t reg, uint16_t val)
{
  uint8_t b[3] = { reg, (uint8_t)(val & 0xFFu), (uint8_t)(val >> 8) };
  return HAL_I2C_Master_Transmit(&hi2c1, MAX17263_ADDR, b, 3, 80);
}

#define REG_STATUS   0x00u
#define REG_REPSOC   0x06u
#define REG_TEMP     0x08u
#define REG_VCELL    0x09u

HAL_StatusTypeDef Gauge_Read(float *soc, float *temp_c, float *vcell_v, uint16_t *status)
{
  uint16_t v;

  if (i2c_r16(REG_STATUS, &v) != HAL_OK) return HAL_ERROR;
  *status = v;

  if (i2c_r16(REG_REPSOC, &v) != HAL_OK) return HAL_ERROR;
  *soc = (float)v / 256.0f;

  if (i2c_r16(REG_TEMP, &v) != HAL_OK) return HAL_ERROR;
  int16_t ts = (int16_t)v;
  *temp_c = (float)ts / 256.0f;

  if (i2c_r16(REG_VCELL, &v) != HAL_OK) return HAL_ERROR;
  *vcell_v = (float)v * 78.125e-6f;

  return HAL_OK;
}

/* Optional: keep as hook; fill exact EZ sequence when you finalize params */
HAL_StatusTypeDef Gauge_EZ_Init(void)
{
  /* Implement later if needed. Return OK for now. */
  return HAL_OK;
}

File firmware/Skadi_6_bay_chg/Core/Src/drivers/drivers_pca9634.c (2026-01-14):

#include "drivers_pca9634.h"
#include "board_io.h"

static HAL_StatusTypeDef w8(uint8_t reg, uint8_t val)
{
  uint8_t b[2] = { reg, val };
  return HAL_I2C_Master_Transmit(&hi2c1, PCA9634_ADDR, b, 2, 80);
}

HAL_StatusTypeDef LedDrv_Init(void)
{
  if (w8(0x00, 0x00) != HAL_OK) return HAL_ERROR; /* MODE1 */
  if (w8(0x01, 0x00) != HAL_OK) return HAL_ERROR; /* MODE2 */

  if (w8(0x14, 0xAA) != HAL_OK) return HAL_ERROR;
  if (w8(0x15, 0xAA) != HAL_OK) return HAL_ERROR;
  if (w8(0x16, 0xAA) != HAL_OK) return HAL_ERROR;
  if (w8(0x17, 0xAA) != HAL_OK) return HAL_ERROR;

  for (uint8_t ch = 0; ch < 16; ch++) {
    uint8_t b[2] = { (uint8_t)(0x02u + ch), 0u };
    if (HAL_I2C_Master_Transmit(&hi2c1, PCA9634_ADDR, b, 2, 80) != HAL_OK) return HAL_ERROR;
  }
  return HAL_OK;
}

HAL_StatusTypeDef LedDrv_Set(uint8_t ch, uint8_t duty)
{
  uint8_t b[2] = { (uint8_t)(0x02u + ch), duty };
  return HAL_I2C_Master_Transmit(&hi2c1, PCA9634_ADDR, b, 2, 80);
}

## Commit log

2025-11-06 ajout du projet KiCad
    [6_bay_charg.kicad_pcb, 6_bay_charg.kicad_sch, MCU_sch.kicad_sch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]
2025-11-18 Revise README for Skadi 6-Bay Smart Charger
    Updated README to reflect project specifications and architecture.
2025-12-04 adding 3.3v buck sch + bay1
    [6_bay_charg.kicad_pcb, 6_bay_charg.kicad_sch, Buck_3.3V_sch.kicad_sch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]
2026-01-07 Update KiCad schematics: dual GPIO charge/discharge per bay
    - Refactored bay power control logic
    - Separated GPIOs for charge and discharge paths
    - Added safe idle state with hardware interlock
    - Improved overall safety and control clarity
    - Updated and exported schematic PDF plots
    [6_bay_charg.kicad_sch, Buck_3.3V_sch.kicad_sch, LEDs_driver.kicad_sch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]
2026-01-14 Integrate fan, USB interface, firmware, and cleaned KiCad schematics
    - Added 12V fan for thermal management
    - Integrated USB interface (hardware and firmware)
    - Added initial firmware implementation
    - Cleaned and refactored KiCad schematics
    - Updated and regenerated schematic PDF plots
    - Updated project README to reflect latest architecture
    [6_bay_charg.kicad_sch, Buck_3.3V_sch.kicad_sch, LEDs_driver.kicad_sch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]
2026-01-14 cleaning up some buckups files
2026-01-14 update_schematics
    plot last updated pdf
    [6_bay_charg.kicad_sch, untitled.kicad_sch]
2026-03-02 updating FSM diagramme
    [6_bay_charg.kicad_sch, MCU_sch.kicad_sch, MUX.kicad_sch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]
2026-03-03 Fixing Buck_3.3V EN
    [Buck_3.3V_sch.kicad_sch, untitled.kicad_sch]
2026-03-04 Add LTspice validation of CHG/DIS switching and hardware interlock
    - Verified Vgs behavior for both PMOS switches
    - Confirmed no CHG/DIS overlap
    - Validated peak and steady-state currents
    - Added simulation file and waveform capture

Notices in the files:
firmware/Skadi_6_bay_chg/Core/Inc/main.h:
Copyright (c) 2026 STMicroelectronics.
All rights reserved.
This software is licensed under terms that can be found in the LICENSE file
